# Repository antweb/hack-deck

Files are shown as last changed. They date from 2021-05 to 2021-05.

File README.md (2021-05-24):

# Hack Deck

A simple macro keyboard designed from scratch.

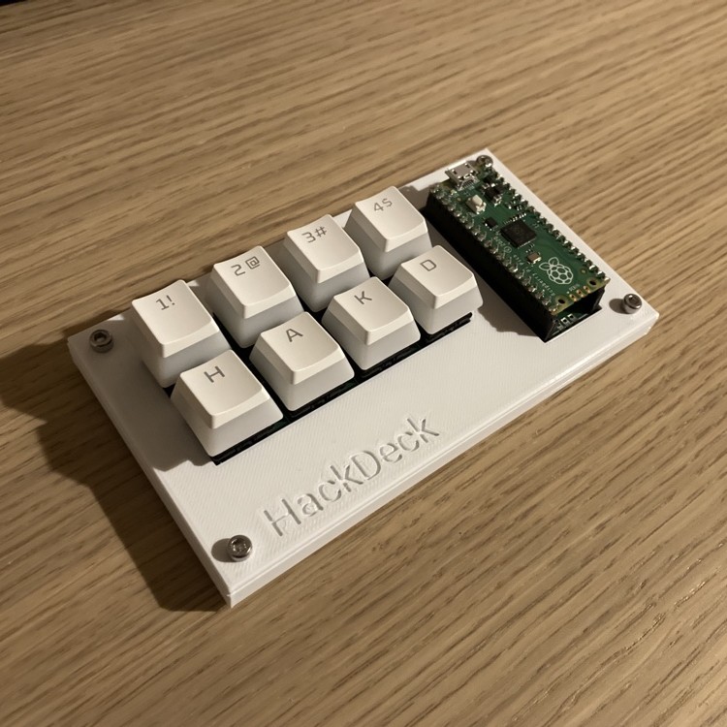
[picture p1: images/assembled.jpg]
Assembled project


## Overview

### Microcontroller
Raspberry Pi Pico running a simple CircuitPython firmware that acts as a USB HID keyboard.

### PCB
The board offers room for eight Cherry MX compatible switches. Each switch is wired to its own GPIO port on the Pico and all share one common ground connector.

### Case
Simple enclosure consisting of a top and bottom half.

## Part List
Other than the board and the case that can be produced from the designs, following parts are needed:
* 1x Raspberry Pi Pico
* 2x 20 pin short female header
* 8x Cherry MX compatible switch
* 8x Cherry MX compatible keycap
* 4x M3x10 screw
* 4x M3 nut

Keyswitches with fixing pins are recommended (e.g. Cherry MX1A-E1NN), as they make it easier to solder them to the PCB. For switches without fixing pins, the soldering aid included in the case designs can be used to align things evenly.

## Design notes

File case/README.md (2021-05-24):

# Case
3D models for case parts.

Same as the PCB, all mounting holes are designed for M3 nuts / screws.

All files saved with FreeCAD 0.19.

### case_bottom
Bottom base that holds the PCB. Has cutouts at the bottom to hold M3 nuts in place.

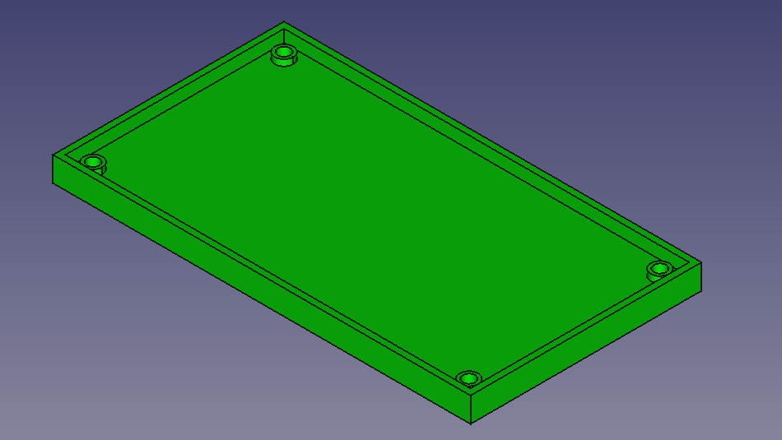
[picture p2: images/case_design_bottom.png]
model Bottom case


### case_top
Optional top cover.

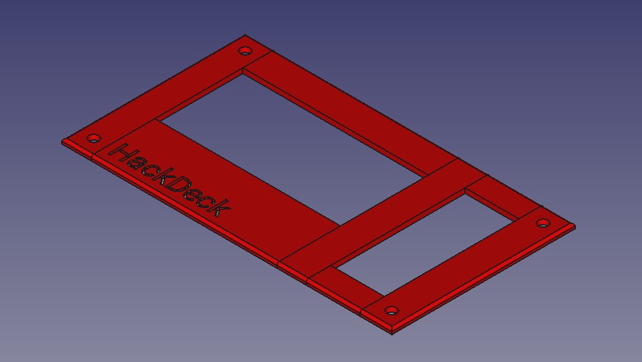
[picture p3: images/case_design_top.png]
model Top cover


### solder_holder
Soldering aid that holds the switches in places and alings them correctly.

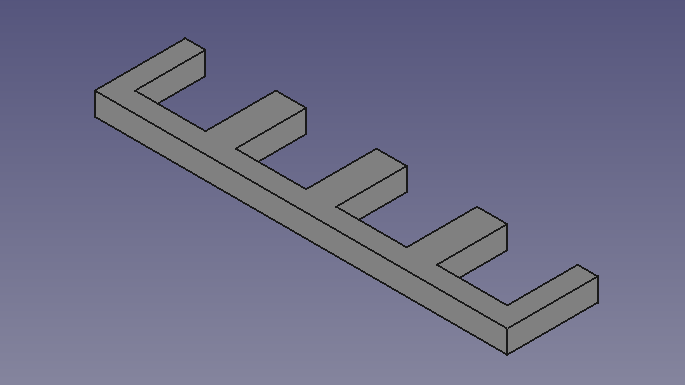
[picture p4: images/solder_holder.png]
model Soldering aid


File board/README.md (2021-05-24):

# PCB
Circuit board design to hold and connect eight keyboard switches and a Raspberry Pi Pico.

Created with KiCad 5.1.10 using [this template](https://github.com/sethhillbrand/kicad_templates/tree/master/AISLER-2Layer).

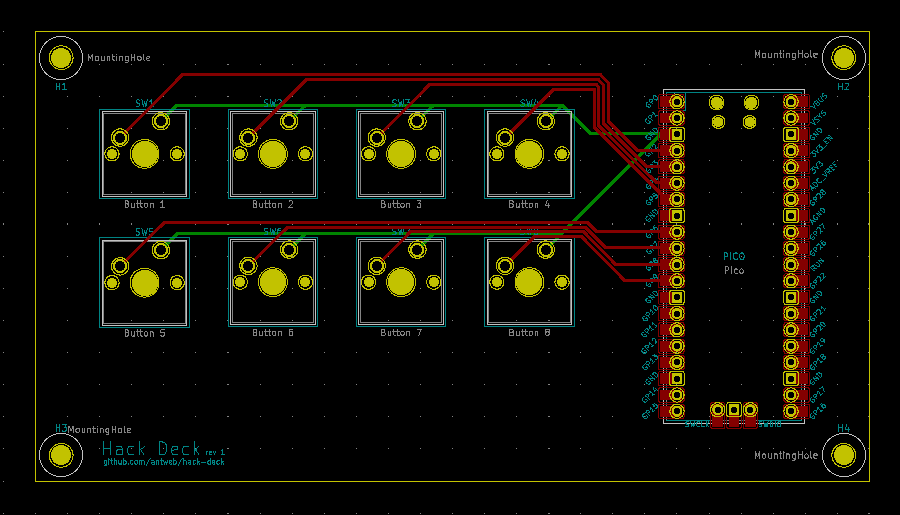
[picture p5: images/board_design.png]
schematic Board schematic


### Footprints
The design uses additional footprint libraries:
* [RP_Silicon_KiCad](https://github.com/HeadBoffin/RP_Silicon_KiCad)
* [Button_Switch_Keyboard.pretty](https://gitlab.com/kicad/libraries/kicad-footprints/-/tree/master/Button_Switch_Keyboard.pretty)

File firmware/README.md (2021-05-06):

# Firmware

A simple macro keyboard firmware. Runs on a Raspberry Pi Pico with CircuitPython.

Requires the [Adafruit CircuitPython HID library](https://github.com/adafruit/Adafruit_CircuitPython_HID) to be installed on the board.

Tested with CircuitPython 6.2.0 and the Adafruit HID library 4.2.0.

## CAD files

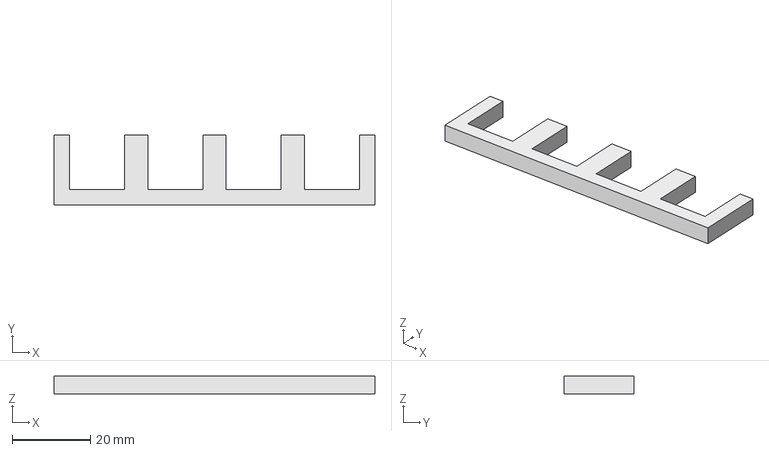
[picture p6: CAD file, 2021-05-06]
case/solder_holder.FCStd
82.0 x 18.0 x 4.50 mm

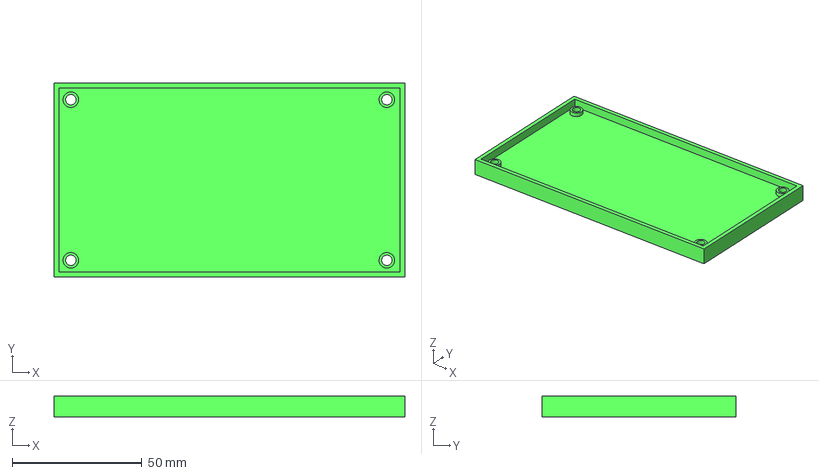
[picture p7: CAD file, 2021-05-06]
case/case_bottom.FCStd
135.5 x 75.0 x 8.00 mm

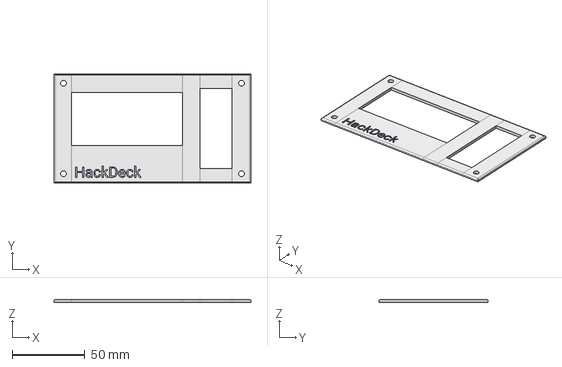
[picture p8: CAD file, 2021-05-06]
case/case_top.FCStd
135.0 x 75.0 x 2.00 mm

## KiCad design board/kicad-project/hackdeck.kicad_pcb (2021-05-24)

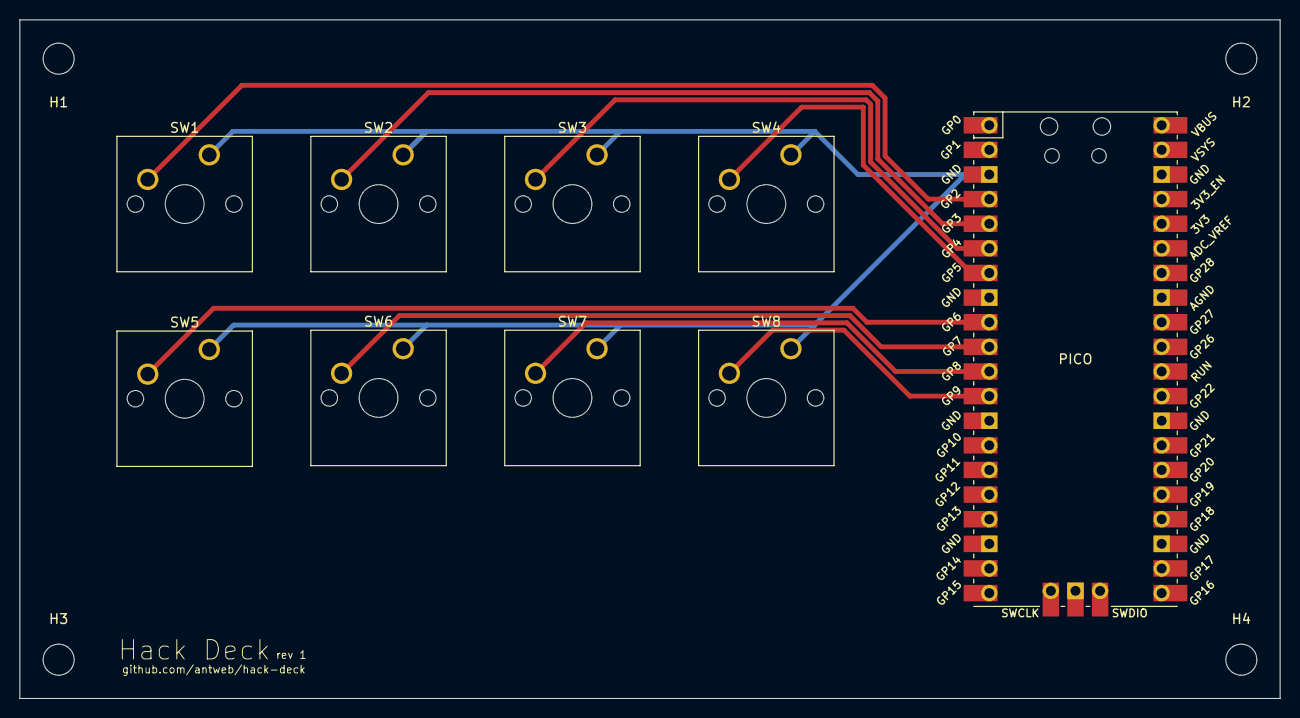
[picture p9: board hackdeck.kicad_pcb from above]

Board: 2 copper layers, 130.0 x 70.0 mm, 13 parts (0 on the bottom side), 9 nets.

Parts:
H1, H2, H3, H4: MountingHole; MountingHole_3.2mm_M3
PICO: Pico; RPi_Pico_SMD_TH
SW1: Button 1; SW_Cherry_MX_1.00u_PCB
SW2: Button 2; SW_Cherry_MX_1.00u_PCB
SW3: Button 3; SW_Cherry_MX_1.00u_PCB
SW4: Button 4; SW_Cherry_MX_1.00u_PCB
SW5: Button 5; SW_Cherry_MX_1.00u_PCB
SW6: Button 6; SW_Cherry_MX_1.00u_PCB
SW7: Button 7; SW_Cherry_MX_1.00u_PCB
SW8: Button 8; SW_Cherry_MX_1.00u_PCB

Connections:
GND: PICO.3, SW1.1, SW2.1, SW3.1, SW4.1, SW5.1, SW6.1, SW7.1, SW8.1
unnamed: PICO.4, SW1.2
unnamed: PICO.5, SW2.2
unnamed: PICO.6, SW3.2
unnamed: PICO.7, SW4.2
unnamed: PICO.9, SW5.2
unnamed: PICO.10, SW6.2
unnamed: PICO.11, SW7.2
unnamed: PICO.12, SW8.2

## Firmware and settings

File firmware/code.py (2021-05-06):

import board
import digitalio
import time
import usb_hid
from adafruit_hid.keyboard import Keyboard
from adafruit_hid.keycode import Keycode
from adafruit_hid.consumer_control import ConsumerControl
from adafruit_hid.consumer_control_code import ConsumerControlCode


kbd = Keyboard(usb_hid.devices)
consumer_control = ConsumerControl(usb_hid.devices)

led = digitalio.DigitalInOut(board.LED)
led.direction = digitalio.Direction.OUTPUT

button1 = digitalio.DigitalInOut(board.GP2)
button2 = digitalio.DigitalInOut(board.GP3)
button3 = digitalio.DigitalInOut(board.GP4)
button4 = digitalio.DigitalInOut(board.GP5)
button5 = digitalio.DigitalInOut(board.GP6)
button6 = digitalio.DigitalInOut(board.GP7)
button7 = digitalio.DigitalInOut(board.GP8)
button8 = digitalio.DigitalInOut(board.GP9)

button1.switch_to_input(pull=digitalio.Pull.UP)
button2.switch_to_input(pull=digitalio.Pull.UP)
button3.switch_to_input(pull=digitalio.Pull.UP)
button4.switch_to_input(pull=digitalio.Pull.UP)
button5.switch_to_input(pull=digitalio.Pull.UP)
button6.switch_to_input(pull=digitalio.Pull.UP)
button7.switch_to_input(pull=digitalio.Pull.UP)
button8.switch_to_input(pull=digitalio.Pull.UP)

cooldown = 0.2

########################################
# Button mapping goes here
########################################


def run_button1():
    consumer_control.send(ConsumerControlCode.PLAY_PAUSE)
    led.value = True


def run_button2():
    consumer_control.send(ConsumerControlCode.SCAN_NEXT_TRACK)
    led.value = True


def run_button3():
    consumer_control.send(ConsumerControlCode.VOLUME_DECREMENT)
    led.value = True


def run_button4():
    consumer_control.send(ConsumerControlCode.VOLUME_INCREMENT)
    led.value = True


def run_button5():
    kbd.press(Keycode.ALT)
    kbd.press(Keycode.Z)
    led.value = True


def run_button6():
    kbd.press(Keycode.ALT)
    kbd.press(Keycode.F1)
    led.value = True


def run_button7():
    kbd.press(Keycode.ALT)
    kbd.press(Keycode.F10)
    led.value = True


def run_button8():
    kbd.press(Keycode.CONTROL)
    kbd.press(Keycode.ALT)
    kbd.press(Keycode.DELETE)
    led.value = True


########################################
# Button mapping end
########################################


while True:
    if not button1.value:
        run_button1()
        kbd.release_all()
        time.sleep(cooldown)
    if not button2.value:
        run_button2()
        kbd.release_all()
        time.sleep(cooldown)
    if not button3.value:
        run_button3()
        kbd.release_all()
        time.sleep(cooldown)
    if not button4.value:
        run_button4()
        kbd.release_all()
        time.sleep(cooldown)
    if not button5.value:
        run_button5()
        kbd.release_all()
        time.sleep(cooldown)
    if not button6.value:
        run_button6()
        kbd.release_all()
        time.sleep(cooldown)
    if not button7.value:
        run_button7()
        kbd.release_all()
        time.sleep(cooldown)
    if not button8.value:
        run_button8()
        kbd.release_all()
        time.sleep(cooldown)
    else:
        led.value = False

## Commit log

2021-05-06 add license for case parts
2021-05-06 add case designs
    [case_bottom.FCStd, case_top.FCStd]
2021-05-06 add design for solder aid
    [solder_holder.FCStd]
2021-05-06 document case designs
2021-05-24 add license for board design
2021-05-24 document board design
2021-05-24 add board designs
    [hackdeck.kicad_pcb, hackdeck.sch]
2021-05-24 add case design images
2021-05-24 add screenshot of board design
2021-05-24 add image of soldering aid
